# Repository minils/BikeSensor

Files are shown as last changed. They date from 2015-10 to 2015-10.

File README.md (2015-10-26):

# BikeSensor
Bicycle based enviroment sensor

Bike Sensor Icon

### General

This project was developed at the University of Freiburg. At the chair of [Embedded Systems].

The board that is powered by the wheels of a bicycle is intended to collect sensor data of the enviroment.
This data is then sent via BLE and further processed by an Android smartphone.

### Version
3.2.0

### Setup

What you need to develop:

- [AndroidStudio]
- [Arduino IDE]
- [Eagle CAD]

### Todos

 - Write Tests
 - Improve BLE connection
 - Add sensors

License
----

GPLv2

[//]: # (These are reference links used in the body of this note and get stripped out when the markdown processor does it's job. There is no need to format nicely because it shouldn't be seen. Thanks SO - http://stackoverflow.com/questions/4823468/store-comments-in-markdown-syntax)

   [AndroidStudio]: <https://developer.android.com/sdk/index.html>
   [Arduino IDE]: <https://www.arduino.cc/en/Main/Software>
   [Eagle CAD]: <https://www.cadsoft.de/download-eagle/>
   [Embedded Systems]: <https://earth.informatik.uni-freiburg.de/>

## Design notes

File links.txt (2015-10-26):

CO Sensor
http://davidhoulding.blogspot.de/2014/03/co-carbon-monoxide-gas-sensor-using.html
https://www.sparkfun.com/products/9403

Ozon Sensor
http://www.ebay.de/itm/SainSmart-MQ131-Gas-Sensor-Ozone-Module-For-Arduino-UNO-Mega2560-R3-Raspberry-Pi-/221441549427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

Spannungsregler
MC34063A
http://electronics.stackexchange.com/questions/97024/how-to-use-boost-step-up-converter-mc34063
https://www.sparkfun.com/products/317
http://www.nomad.ee/micros/mc34063a/index.shtml

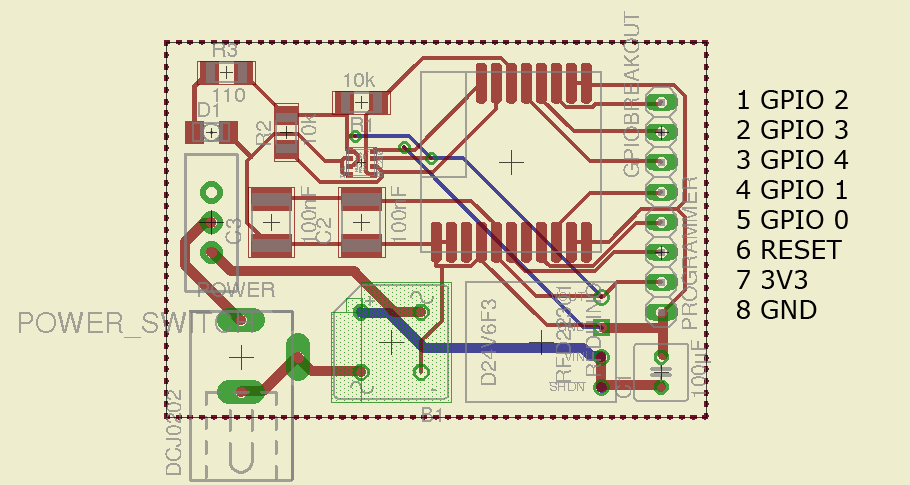
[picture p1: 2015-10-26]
Pins.png

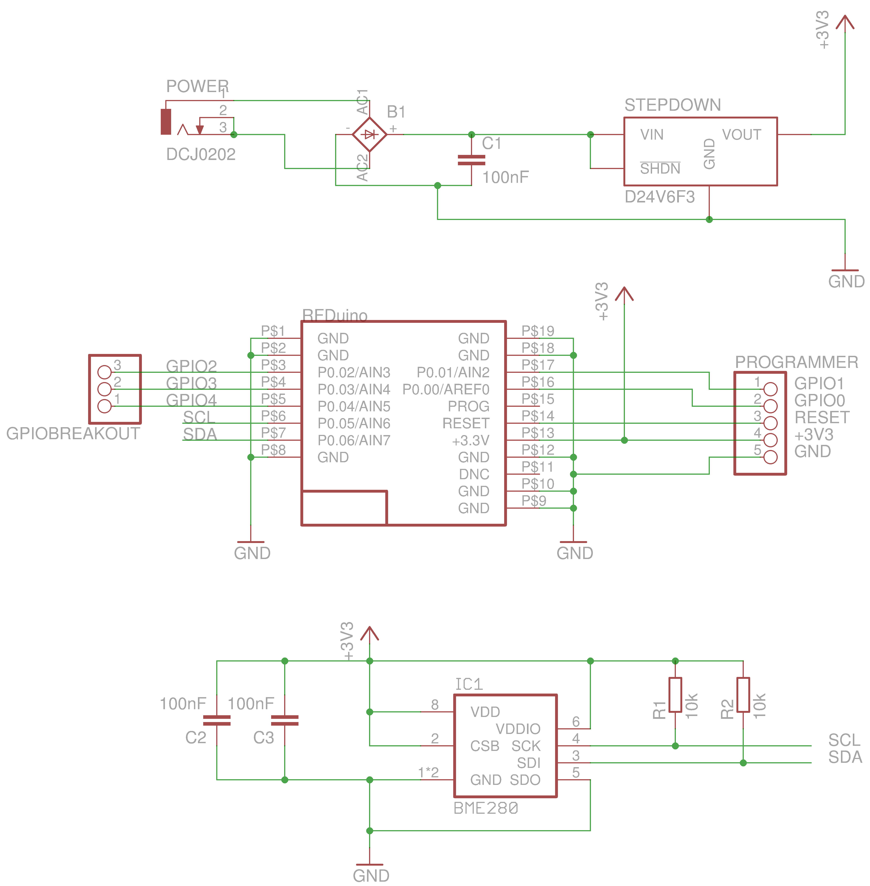
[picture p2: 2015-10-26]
Eagle/export_schaltplan.png

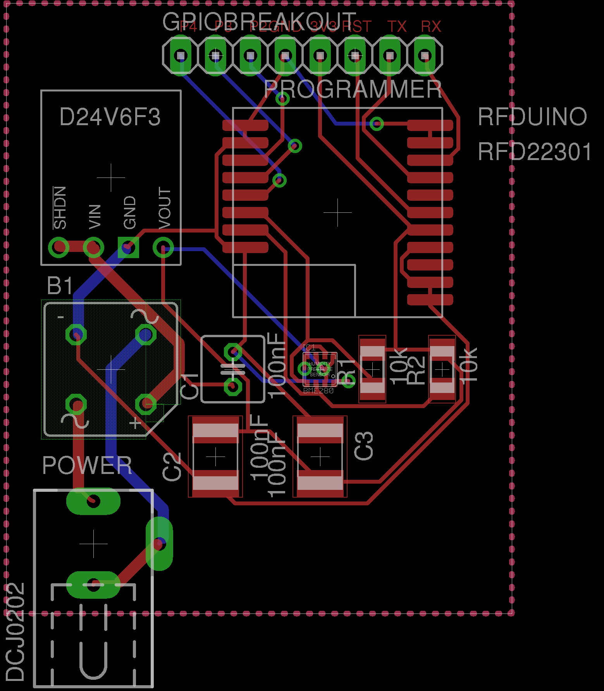
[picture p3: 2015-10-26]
Eagle/export.png

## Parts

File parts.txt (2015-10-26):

Pololu 3.3V 600mA Step-Down Spannungsregler D24V6F3
Kondensator	100 µF 35 V
Bosch BME280
Gleichrichter B80C1500 RUND
SMD 1/4W 100K :: SMD-Chip-Widerstand, Bauform 1206, 100 K-Ohm
SMD-1812 100N :: Wima-SMD-Kondensator, Bauform 1812, 100nF
RFD22301 (RFDuino)
BL 1X10G 2,00

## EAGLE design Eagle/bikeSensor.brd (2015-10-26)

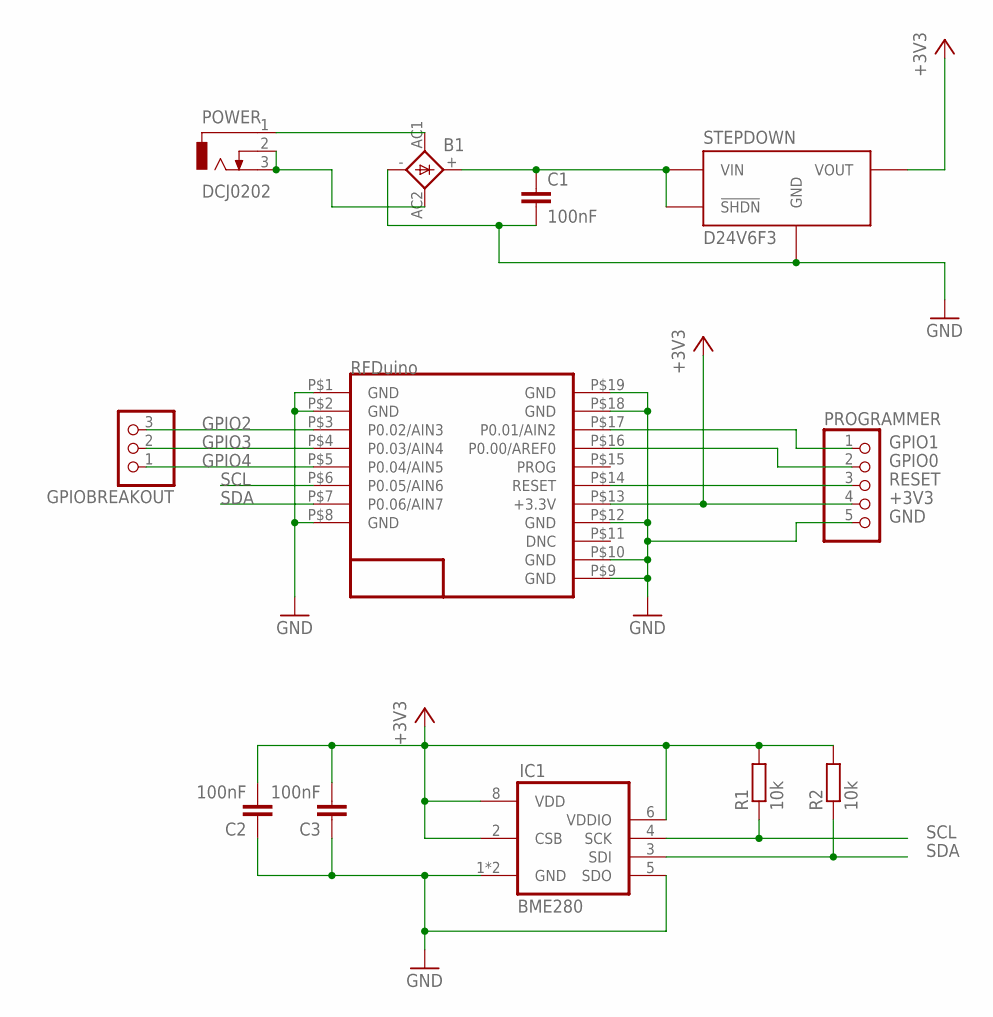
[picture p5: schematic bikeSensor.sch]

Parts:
B1: 1KAB
C1: 100nF; C025-050X050
C2, C3: 100nF; C1812
GPIOBREAKOUT: PINHD-1X3; 1X03
IC1: BME280
POWER: DCJ0202
PROGRAMMER: PINHD-1X5; 1X05
R1, R2: 10k; R1206
RFDUINO: RFD22301; RFD21733
STEPDOWN: D24V6F3

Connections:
+3V3: C2.2, C3.2, IC1.2 (CSB), IC1.6 (VDDIO), IC1.8 (VDD), PROGRAMMER.4, R1.2, R2.2, RFDUINO.P$13 (+3.3V), STEPDOWN.VOUT
GND: B1.-, C1.2, C2.1, C3.1, IC1.1 (GND), IC1.5 (SDO), IC1.7 (GND), PROGRAMMER.5, RFDUINO.P$1 (GND), RFDUINO.P$2 (GND), RFDUINO.P$8 (GND), RFDUINO.P$9 (GND), RFDUINO.P$10 (GND), RFDUINO.P$12 (GND), RFDUINO.P$18 (GND), RFDUINO.P$19 (GND), STEPDOWN.GND
GPIO0: PROGRAMMER.2, RFDUINO.P$16 (P0.00/AREF0)
GPIO1: PROGRAMMER.1, RFDUINO.P$17 (P0.01/AIN2)
GPIO2: GPIOBREAKOUT.3, RFDUINO.P$3 (P0.02/AIN3)
GPIO3: GPIOBREAKOUT.2, RFDUINO.P$4 (P0.03/AIN4)
GPIO4: GPIOBREAKOUT.1, RFDUINO.P$5 (P0.04/AIN5)
unnamed: B1.AC2, POWER.2, POWER.3
unnamed: B1.AC1, POWER.1
unnamed: B1.+, C1.1, STEPDOWN.!SHDN, STEPDOWN.VIN
RESET: PROGRAMMER.3, RFDUINO.P$14 (RESET)
SCL: IC1.4 (SCK), R1.1, RFDUINO.P$6 (P0.05/AIN6)
SDA: IC1.3 (SDI), R2.1, RFDUINO.P$7 (P0.06/AIN7)

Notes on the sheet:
RFDuino

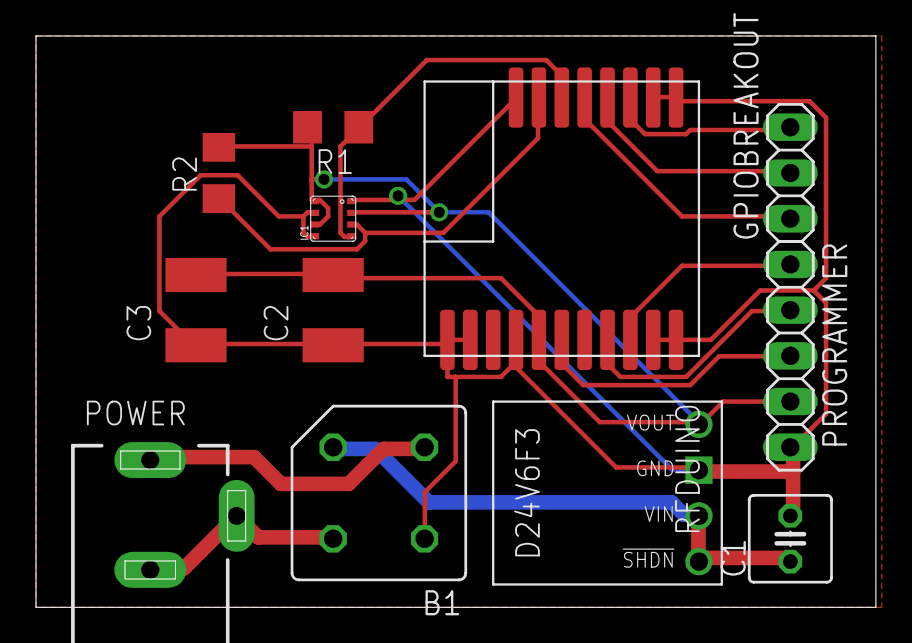
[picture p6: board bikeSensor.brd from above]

Board: 2 copper layers, 46.7 x 31.7 mm, 12 parts (0 on the bottom side), 13 nets.

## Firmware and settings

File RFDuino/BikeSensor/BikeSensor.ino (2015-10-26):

/*

Author: Nils Schwabe
Last change: 19.08.2015

BikeSensor
----------

Code to read sensor data from BME280 and send it via BLE
to the corresponding Android app.

Some parts of the code were adapted from the examples of
the BME280 MOD-1022 demo from www.embeddedadventures.com

Android app availible on Github: <missing link>
Board layout availible on Github: <missing link>
*/


#include <RFduinoBLE.h>
#include <BME280_MOD-1022.h>
#include <Wire.h>

#define MAX 100
#define DELAY 3

int data[MAX];
int n = 0;

boolean isConnected = false;

void setup() {
  // setup i2c
  Wire.begin();

  // setup sensor
  // need to read the NVM compensation parameters
  BME280.readCompensationParams();
  
  // Need to turn on 1x oversampling, default is os_skipped, which means it doesn't measure anything
  BME280.writeOversamplingPressure(os1x);  // 1x over sampling (ie, just one sample)
  BME280.writeOversamplingTemperature(os1x);
  BME280.writeOversamplingHumidity(os1x);

  // setup BLE
  RFduinoBLE.advertisementData = "m";
  RFduinoBLE.deviceName = "Bike Sensor";
  RFduinoBLE.advertisementInterval = 100;  // ms
  RFduinoBLE.txPowerLevel = -8;  // power  -20, -16, -8, -4, 0, +4
  RFduinoBLE.begin();

  Serial.begin(9600);
  Serial.println("Welcome to BikeSensor");
  Serial.println("Initialization done.");
}

void loop() {
  if (isConnected) {
    Serial.println("isConnected.. sendData()");
    sendData();
  }
  performMeasurements();
  //RFduino_ULPDelay(INFINITE);  // Stay in ultra low power mode until interrupt from the BLE or pinWake()
  delay(DELAY * 1000);
}

void RFduinoBLE_onConnect(){
  Serial.println("Connected");
  isConnected = true;
}

void RFduinoBLE_onDisconnect() {
  Serial.println("Disconnected");
  isConnected = false;
}

void sendData() {
  for (int i = 0; i < n; i++) {
    int waiting = 0;
    while (!RFduinoBLE.sendInt(data[i]) && waiting < 10000) {
      waiting++;
    }
  }
  Serial.print("DONE sending ");
  Serial.print(n);
  Serial.println(" chunks");
  n = 0;
}

void performMeasurements() {
  Serial.println("Measuring...");
  // example of a forced sample.  After taking the measurement the chip goes back to sleep
  BME280.writeMode(smForced);
  while (BME280.isMeasuring());
  BME280.readMeasurements();
  if (n + 1 < MAX) {
    data[n] = millis();
    data[n + 1] = BME280.getTemperatureMostAccurate() * 10.0;
    Serial.print(data[n]/1000);
    Serial.print("s - ");
    Serial.print("Temp: ");
    Serial.println(data[n+1]);
    n += 2;
  } else {
    n = 0;
    // buffer is full... TODO
  }
}
